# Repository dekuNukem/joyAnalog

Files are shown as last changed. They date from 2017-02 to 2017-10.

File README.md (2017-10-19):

# Custom circuit board for Joycon input automation



joyAnalog is a custom board with 12 analog switches and 2 12-bit DAC channels. Its main purpose is for automating Nintendo Switch Joycon inputs, and maybe TAS as well. 

joyAnalog presents itself to PC as a virtual USB serial port, so no special drivers are needed. Simply connect the button and joystick test points to the headers to allow the Joycon be controlled from a PC.

## Specs

* STM32F072C8T6 microcontroller, 16KB RAM, 64KB ROM
* 2x ADG714 SPI analog switch
* 1KB I2C EEPROM
* Automatic power switching
* User LED and button

## Header mappings

See [this PDF](datasheets/header_mapping.pdf).

## Twitch Plays Nintendo Switch

I dug up and reused a portion of my old code for TwitchPlaysPokemonX, [see here](./TwitchPlaysNintendoSwitch).

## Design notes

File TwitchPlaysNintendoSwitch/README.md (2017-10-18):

# Twitch Plays Nintendo Switch

This is actually a simplified version of the code used during Twitch Plays Pokemon X back in 2014. To keep it simple I used  tkinter for the command scroller. 

To use it:

* Connect the two correctly configured NintenDAC mini board to the computer.

* Open up `launch.py` in an editor and configure the username, oauth, chat channel and serial port name.

* Open up `banned_user.txt` and `disabled_cmd.txt` and fill them in as you wish. These can be updated while main script is running too.

* Run `python3 launch.py`

This script was tested under windows 10, it should work in macOS and linux too.

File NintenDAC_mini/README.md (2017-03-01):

## NintenDAC mini

This is the board that's to be used on modifying the Joycon. It's small enough to be taped to the back of each one.



* 48MHz STM32F072C8T6 microcontroller, 64KB flash, 16KB RAM.
* Built-in 2-channel 12-bit DAC.
* 1KB I2C EEPROM, user button, user LED.
* 28 GPIOs(or 32 using internal oscillators), BOOT0, RESET, VBAT, and SWD.
* USB for power and communication, standby wakeup on USB connection.
* Board size 2.5 x 4.1 cm, 1 x 1.6 inch.

## Command protocol

NintenDAC mini uses a simple serial command protocol. To use it open the port at any baud rate, then send a command in ASCII string. The board will send a response back.

Commands should be in lower case, and end with a single `\n`.

### Commands

**command**|**arguments**|**remark**|**response**|**example**
:-----:|:-----:|:-----:|:-----:|:-----:
`eepinit`|none|initializes EEPROM to default value|`eepinit OK`|`eepinit`
`settype`|l / r|set this board as left or right Joycon|`settype OK`|`settype l`
`whoami`|none|see which side is this board|A string containing `LEFT` or `RIGHT`; `unknown` if incorrectly set up|`whoami`
`bh`|button args (see below)|hold button|`bh OK` if no error; `ERROR`  otherwise|`bh a b x`
`br`|button args (see below)|release button|`br OK` if no error; `ERROR` otherwise|`br a b x`
`bra`|none|release all buttons on this board|`bra OK`|`bra`
`sh`|x y|move stick to x and y value. x y should be between 0 and 255 inclusive; 127 is netural position|`bh OK`|`sh 127 245`
`sr`|none|move stick back to netural position|`br OK`|`sr`
`sd`|none|stick disengage|`sd OK`|`sd`
`reset`|none|release all buttons as well as disengage the stick|`reset OK`|`reset`

### Button args

**arg**|**button**
:-----:|:-----:
`du`|D-pad up
`dd`|D-pad down
`dl`|D-pad left
`dr`|D-pad right
`ls`|L button
`zl`|ZL button
`-`|minus button 
`cap`|capture button
`lsl`|left Joycon SL button
`lsr`|left Joycon SR button
`syncl`|left Joycon SYNC button
`sbl`|left Joycon stick button
`a`|A button
`b`|B button
`x`|X button
`y`|Y button
`rs`|R button
`zr`|ZR button
`+`|plus button
`h`|home button
`rsl`|right Joycon SL button
`rsr`|right Joycon SR button
`syncr`|right Joycon SYNC button
`sbr`|right Joycon stick button

### A few words about commands

* `sh` and `sr` will take over the control stick, meaning the input won't change when you move the stick with your finger when those commands are active. To get back to manual control use `sd`

* Not all buttons are available on one board. For example if you try to `bh a` on a left Joycon board, you will get an error because there is no A button on left Joycon.

* `bh` and `br` can have one or multiple arguments, as long as they are all valid. So you can have `bh a` or `bh a b x y zr h +` etc. The max number of arguments is 16.

## NintenDAC Python3 library

I also wrote a [python3 library](./pythonlib) so you don't have to remember all the commands above. It requires `pyserial`.

A simple example:

```
import ndacmini

switch = ndacmini.ndacmini("COM5", "COM6")
switch.connect()

switch.button_hold(['a', 'b', 'zl', 'zr'])
switch.stick_hold('l', 64, 192)
switch.reset()
switch.disconnect()

```

A more detailed example with comments can be found [here](./pythonlib/example.py)

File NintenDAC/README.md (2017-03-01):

## NintenDAC

This is the bigger board that could be used on modifying the pro controller, or the console itself. It has more GPIOs than the mini, and has 10 channels of high speed DAC output.



* 48MHz STM32F072R8T6 microcontroller, 64KB flash, 16KB RAM.
* MAX5723/MAX5724/MAX5725 8-channel high-speed SPI DAC + 2-channel built-in DAC.
* 1KB I2C EEPROM, user button, user LED.
* 36 GPIOs(or 40 using internal oscillators), BOOT0, RESET, VBAT, and SWD.
* USB for power and communication, standby wakeup on USB connection.
* Board size 4.1 x 4.1 cm, or 1.65 x 1.65 inch.

## Command protocol

NintenDAC uses a simple serial command protocol. To use it open the port at any baud rate, then send a command in ASCII string. The board will send a respond back.

Commands should be in lower case, and end with a single `\n`.

### Commands

**command**|**arguments**|**remark**|**response**|**example**
:-----:|:-----:|:-----:|:-----:|:-----:
`eepinit`|none|initializes EEPROM to default value|`eepinit OK`|`eepinit`
`settype`|l / r|set this board as left or right Joycon|`settype OK`|`settype l`
`whoami`|none|see which side is this board|A string containing `LEFT` or `RIGHT`; `unknown` if incorrectly set up|`whoami`
`bh`|button args (see below)|hold button|`bh OK` if no error; `ERROR`  otherwise|`bh a b x`
`br`|button args (see below)|release button|`br OK` if no error; `ERROR` otherwise|`br a b x`
`bra`|none|release all buttons on this board|`bra OK`|`bra`
`reset`|none|release all buttons as well as disengage the stick|`reset OK`|`reset`

---under construction---under construction---

### Button args

**arg**|**button**
:-----:|:-----:
`du`|D-pad up
`dd`|D-pad down
`dl`|D-pad left
`dr`|D-pad right
`ls`|L button
`zl`|ZL button
`-`|minus button 
`cap`|capture button
`sbl`|left stick button
`a`|A button
`b`|B button
`x`|X button
`y`|Y button
`rs`|R button
`zr`|ZR button
`+`|plus button
`h`|home button
`sbr`|right stick button
`sync`|SYNC button

### A few words about commands

* `sh` and `sr` will take over the control stick, meaning the input won't change when you move the stick with your finger when those commands are active. To get back to manual control use `sd`

* `bh` and `br` can have one or multiple arguments, as long as they are all valid. So you can have `bh a` or `bh a b x y zr h +` etc. The max number of arguments is 16.

---under construction---under construction---

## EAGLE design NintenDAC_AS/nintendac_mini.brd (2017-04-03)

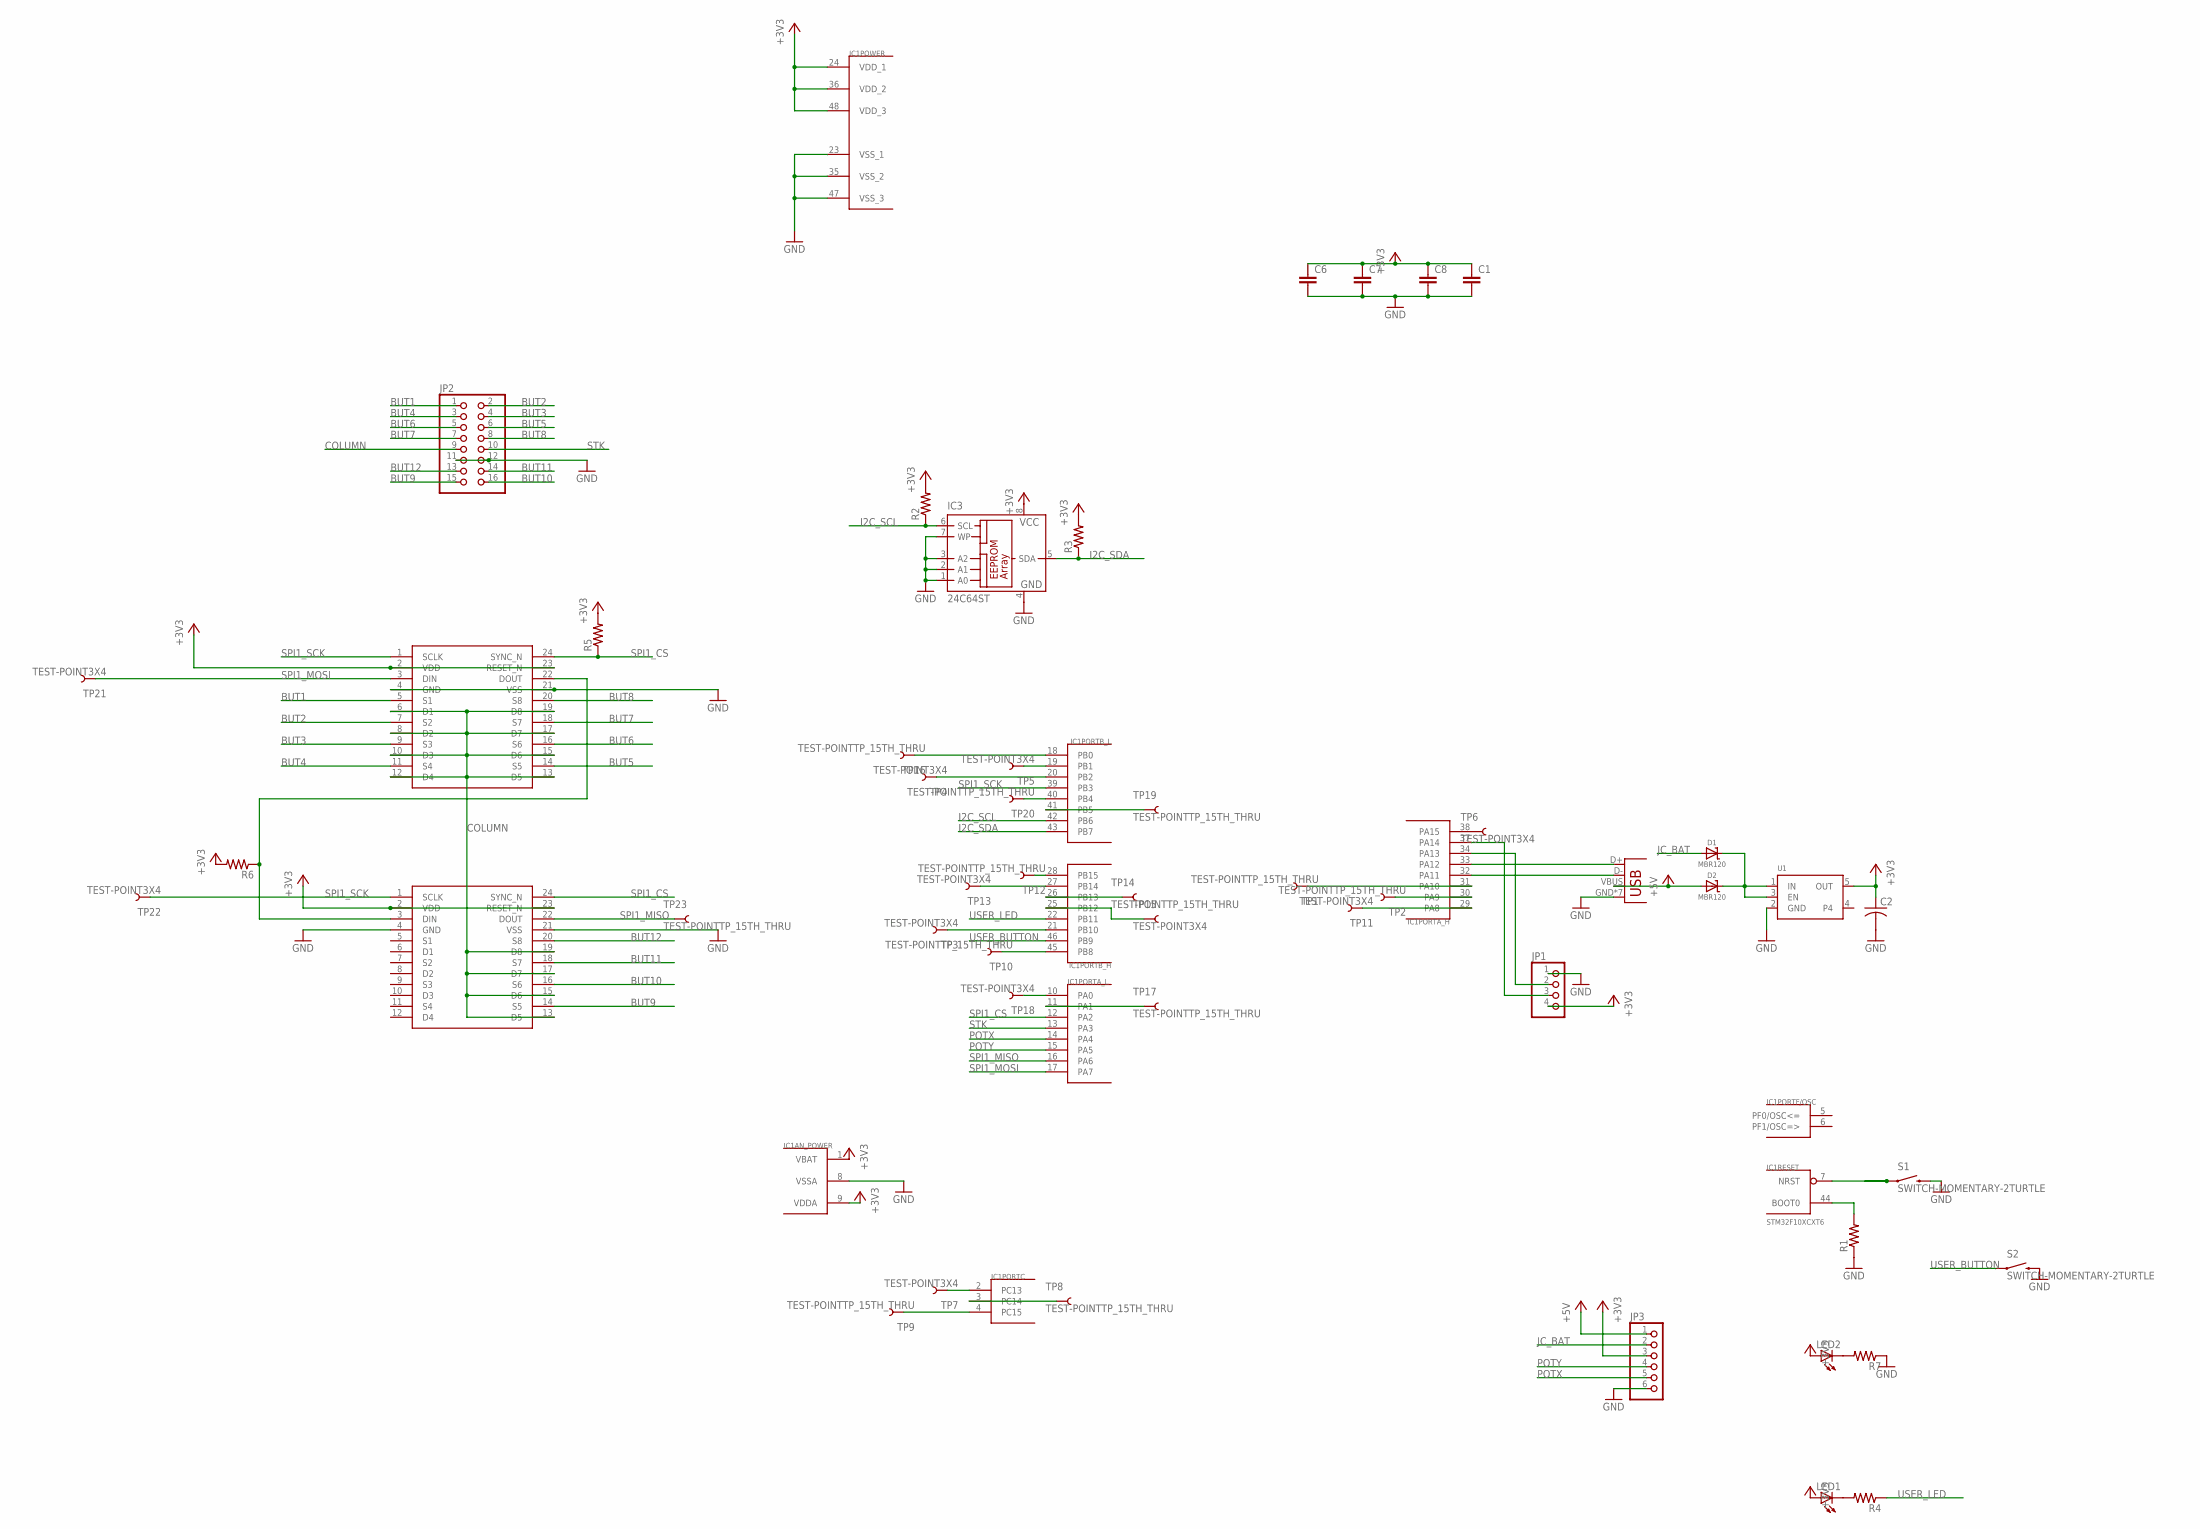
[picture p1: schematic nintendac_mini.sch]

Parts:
C1, C6, C7, C8: CAP0805; 0805
C2: C-USC1210; C1210
D1, D2: MBR120; SOD-123
IC1: STM32F10XCXT6; TQFP48
IC3: 24C64ST; TSSOP8
JP1: PINHD-1X4; 1X04
JP2: PINHD-2X8; 2X08
JP3: PINHD-1X6CB; 1X06-CLEANBIG
LED1, LED2: LEDCHIP-LED0805; CHIP-LED0805
R1, R2, R3, R4, R5, R6, R7: RESISTOR0805-RES; 0805
S1, S2: SWITCH-MOMENTARY-2TURTLE; KMR2
TP1, TP2, TP8, TP9, TP10, TP12, TP14, TP16, TP17, TP19, TP20, TP23: TEST-POINTTP_15TH_THRU; TP_15TH
TP3, TP4, TP5, TP6, TP7, TP11, TP13, TP15, TP18, TP21, TP22: TEST-POINT3X4; PAD.03X.04
U1: VREG_SOT23-5; SOT23-5
U$3, U$4: ADG714_DEV; TSSOP-24
X1: USB-MICROB

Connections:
+3V3: C1.1, C2.1, C6.1, C7.1, C8.1, IC1.1 (VBAT), IC1.9 (VDDA), IC1.24 (VDD_1), IC1.36 (VDD_2), IC1.48 (VDD_3), IC3.8 (VCC), JP1.4, JP3.3, LED1.A, LED2.A, R2.2, R3.2, R5.2, R6.2, U1.5 (OUT), U$3.2 (VDD), U$3.23 (RESET_N), U$4.2 (VDD), U$4.23 (RESET_N)
+5V: D2.A, JP3.1, X1.VBUS
BUT1: JP2.1, U$3.5 (S1)
BUT2: JP2.2, U$3.7 (S2)
BUT3: JP2.4, U$3.9 (S3)
BUT4: JP2.3, U$3.11 (S4)
BUT5: JP2.6, U$3.14 (S5)
BUT6: JP2.5, U$3.16 (S6)
BUT7: JP2.7, U$3.18 (S7)
BUT8: JP2.8, U$3.20 (S8)
BUT9: JP2.15, U$4.14 (S5)
BUT10: JP2.16, U$4.16 (S6)
BUT11: JP2.14, U$4.18 (S7)
BUT12: JP2.13, U$4.20 (S8)
COLUMN: JP2.9, U$3.6 (D1), U$3.8 (D2), U$3.10 (D3), U$3.12 (D4), U$3.13 (D5), U$3.15 (D6), U$3.17 (D7), U$3.19 (D8), U$4.13 (D5), U$4.15 (D6), U$4.17 (D7), U$4.19 (D8)
GND: C1.2, C2.2, C6.2, C7.2, C8.2, IC1.8 (VSSA), IC1.23 (VSS_1), IC1.35 (VSS_2), IC1.47 (VSS_3), IC3.1 (A0), IC3.2 (A1), IC3.3 (A2), IC3.4 (GND), IC3.7 (WP), JP1.1, JP2.11, JP2.12, JP3.6, R1.1, R7.1, S1.3 (2), S2.3 (2), U1.2 (GND), U$3.4 (GND), U$3.21 (VSS), U$4.4 (GND), U$4.21 (VSS), X1.GND, X1.P1 (GND), X1.P2 (GND), X1.P3 (GND), X1.P4 (GND), X1.P5 (GND), X1.P6 (GND)
I2C_SCL: IC1.42 (PB6), IC3.6 (SCL), R2.1
I2C_SDA: IC1.43 (PB7), IC3.5 (SDA), R3.1
JC_BAT: D1.A, JP3.2
unnamed: IC1.7 (NRST), S1.1
unnamed: IC1.44 (BOOT0), R1.2
unnamed: LED1.C, R4.2
unnamed: IC1.33 (PA12), X1.D+
unnamed: R6.1, U$3.22 (DOUT), U$4.3 (DIN)
unnamed: IC1.30 (PA9), TP2.P$1
unnamed: IC1.32 (PA11), X1.D-
unnamed: IC1.34 (PA13), JP1.2
unnamed: IC1.37 (PA14), JP1.3
unnamed: IC1.31 (PA10), TP1.P$1
unnamed: IC1.20 (PB2), TP4.P$1
unnamed: IC1.19 (PB1), TP5.P$1
unnamed: IC1.21 (PB10), TP3.P$1
unnamed: IC1.38 (PA15), TP6.P$1
unnamed: IC1.2 (PC13), TP7.P$1
unnamed: IC1.3 (PC14), TP8.P$1
unnamed: IC1.4 (PC15), TP9.P$1
unnamed: IC1.45 (PB8), TP10.P$1
unnamed: IC1.29 (PA8), TP11.P$1
unnamed: IC1.28 (PB15), TP12.P$1
unnamed: IC1.27 (PB14), TP13.P$1
unnamed: IC1.26 (PB13), TP14.P$1
unnamed: IC1.25 (PB12), TP15.P$1
unnamed: IC1.18 (PB0), TP16.P$1
unnamed: IC1.10 (PA0), TP18.P$1
unnamed: IC1.11 (PA1), TP17.P$1
unnamed: IC1.40 (PB4), TP20.P$1
unnamed: IC1.41 (PB5), TP19.P$1
unnamed: LED2.C, R7.2
unnamed: D1.C, D2.C, U1.1 (IN), U1.3 (EN)
POTX: IC1.14 (PA4), JP3.5
POTY: IC1.15 (PA5), JP3.4
SPI1_CS: IC1.12 (PA2), R5.1, U$3.24 (SYNC_N), U$4.24 (SYNC_N)
SPI1_MISO: IC1.16 (PA6), TP23.P$1, U$4.22 (DOUT)
SPI1_MOSI: IC1.17 (PA7), TP21.P$1, U$3.3 (DIN)
SPI1_SCK: IC1.39 (PB3), TP22.P$1, U$3.1 (SCLK), U$4.1 (SCLK)
STK: IC1.13 (PA3), JP2.10
USER_BUTTON: IC1.46 (PB9), S2.1
USER_LED: IC1.22 (PB11), R4.1

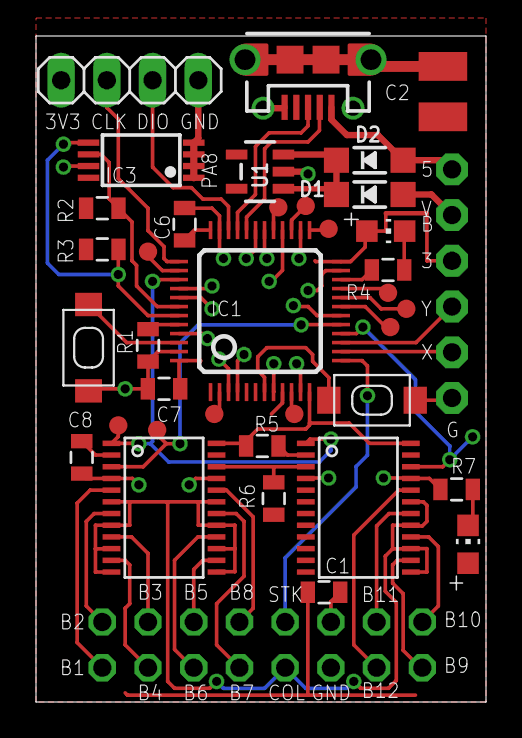
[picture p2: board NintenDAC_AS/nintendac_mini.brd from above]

Board: 2 copper layers, 25.0 x 37.0 mm, 50 parts (0 on the bottom side), 58 nets.

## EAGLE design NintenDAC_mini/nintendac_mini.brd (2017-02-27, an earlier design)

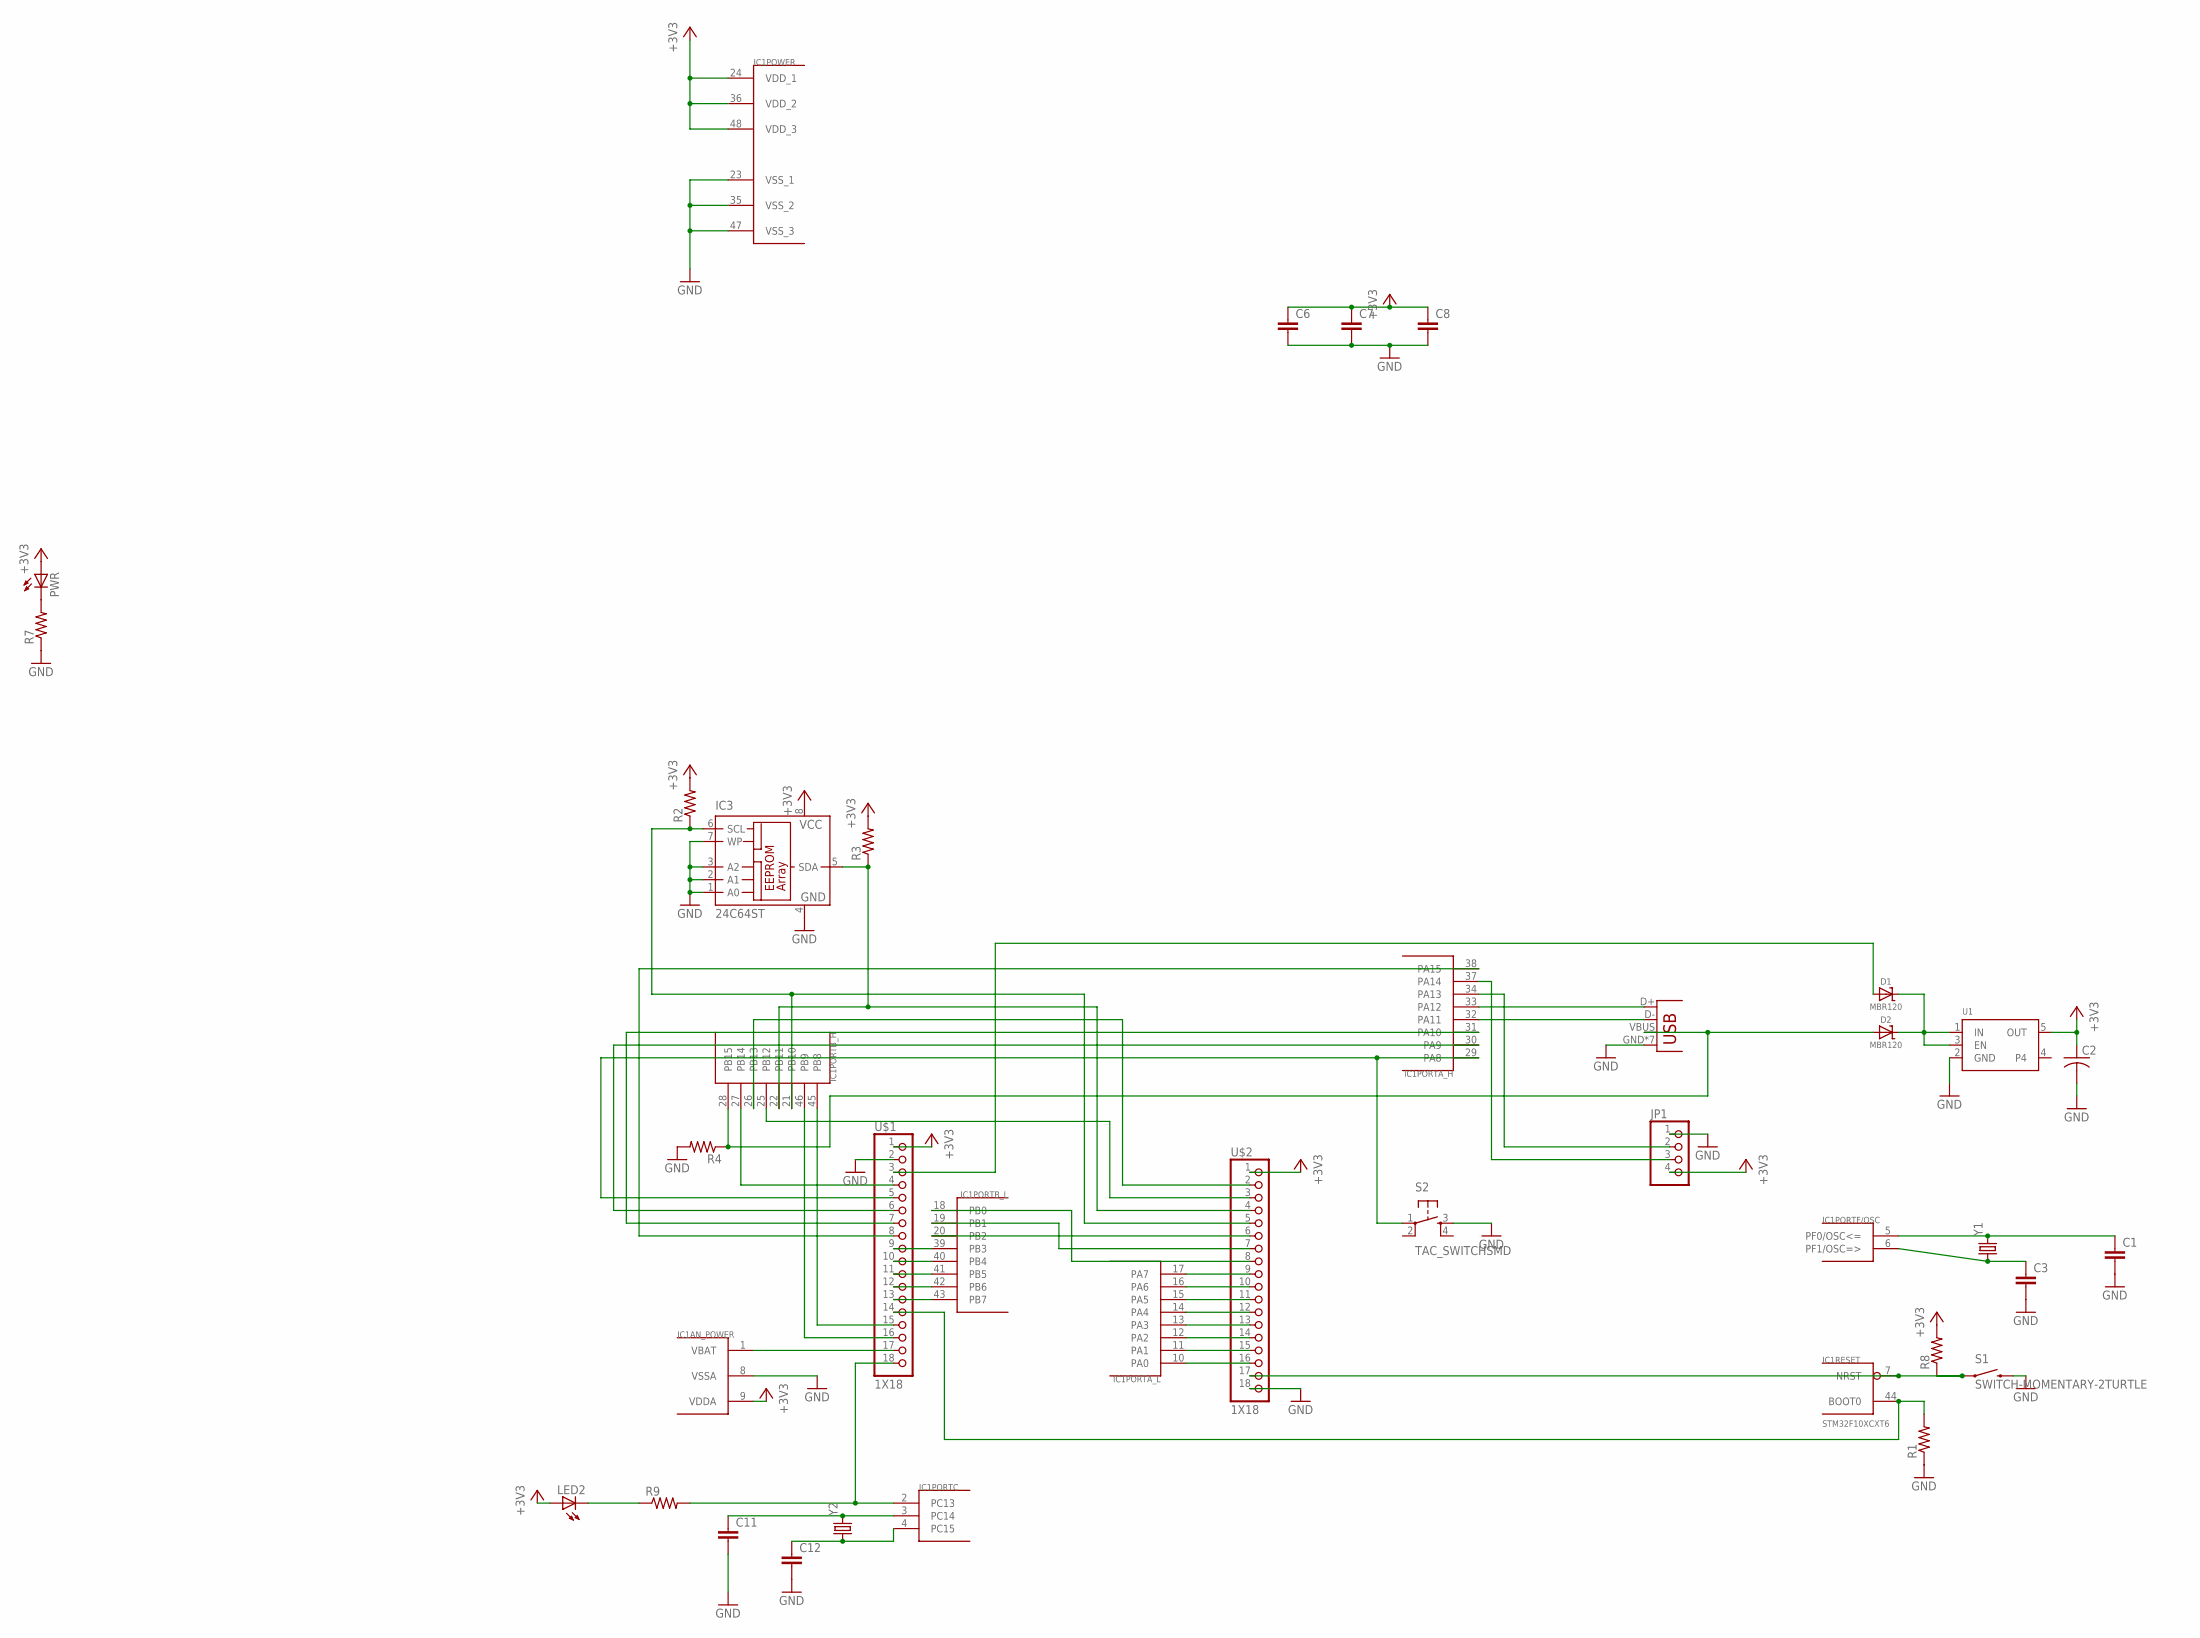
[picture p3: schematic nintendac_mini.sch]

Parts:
C1, C3, C6, C7, C8, C11, C12: CAP0805; 0805
C2: C-USC1210; C1210
D1, D2: MBR120; SOD-123
IC1: STM32F10XCXT6; TQFP48
IC3: 24C64ST; TSSOP8
JP1: PINHD-1X4; 1X04
LED2: LEDCHIP-LED0805; CHIP-LED0805
PWR: LEDCHIP-LED0805; CHIP-LED0805
R1, R2, R3, R4, R7, R8, R9: RESISTOR0805-RES; 0805
S1: SWITCH-MOMENTARY-2TURTLE; KMR2
S2: TAC_SWITCHSMD; TACTILE-SWITCH-SMD
U1: VREG_SOT23-5; SOT23-5
U$1, U$2: 1X18
X1: USB-MICROB
Y1: CRYSTALHC49US; HC49US
Y2: CRYSTALTC26H_EZ; TC26HEZ

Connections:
+3V3: C2.1, C6.1, C7.1, C8.1, IC1.9 (VDDA), IC1.24 (VDD_1), IC1.36 (VDD_2), IC1.48 (VDD_3), IC3.8 (VCC), JP1.4, LED2.A, PWR.A, R2.2, R3.2, R8.2, U1.5 (OUT), U$1.1, U$2.1
GND: C1.2, C2.2, C3.2, C6.2, C7.2, C8.2, C11.2, C12.2, IC1.8 (VSSA), IC1.23 (VSS_1), IC1.35 (VSS_2), IC1.47 (VSS_3), IC3.1 (A0), IC3.2 (A1), IC3.3 (A2), IC3.4 (GND), IC3.7 (WP), JP1.1, R1.1, R4.2, R7.1, S1.3 (2), S2.3, U1.2 (GND), U$1.2, U$2.18, X1.GND, X1.P1 (GND), X1.P2 (GND), X1.P3 (GND), X1.P4 (GND), X1.P5 (GND), X1.P6 (GND)
unnamed: IC1.7 (NRST), R8.1, S1.1, U$2.17
unnamed: D1.A, U$1.3
unnamed: IC1.44 (BOOT0), R1.2, U$1.14
unnamed: IC1.33 (PA12), X1.D+
unnamed: C1.1, IC1.5 (PF0/OSC<=), Y1.2
unnamed: C3.1, IC1.6 (PF1/OSC=>), Y1.1
unnamed: IC1.32 (PA11), X1.D-
unnamed: IC1.34 (PA13), JP1.2
unnamed: IC1.37 (PA14), JP1.3
unnamed: IC1.10 (PA0), U$2.16
unnamed: IC1.11 (PA1), U$2.15
unnamed: IC1.12 (PA2), U$2.14
unnamed: IC1.13 (PA3), U$2.13
unnamed: IC1.14 (PA4), U$2.12
unnamed: IC1.15 (PA5), U$2.11
unnamed: IC1.16 (PA6), U$2.10
unnamed: IC1.17 (PA7), U$2.9
unnamed: IC1.21 (PB10), IC3.6 (SCL), R2.1, U$2.5
unnamed: IC1.22 (PB11), IC3.5 (SDA), R3.1, U$2.4
unnamed: IC1.18 (PB0), U$2.8
unnamed: IC1.19 (PB1), U$2.7
unnamed: IC1.20 (PB2), U$2.6
unnamed: IC1.43 (PB7), U$1.13
unnamed: IC1.42 (PB6), U$1.12
unnamed: IC1.41 (PB5), U$1.11
unnamed: IC1.40 (PB4), U$1.10
unnamed: PWR.C, R7.2
unnamed: C11.1, IC1.3 (PC14), Y2.2
unnamed: C12.1, IC1.4 (PC15), Y2.1
unnamed: IC1.39 (PB3), U$1.9
unnamed: D1.C, D2.C, U1.1 (IN), U1.3 (EN)
unnamed: IC1.2 (PC13), R9.2, U$1.18
unnamed: IC1.1 (VBAT), U$1.17
unnamed: IC1.46 (PB9), U$1.16
unnamed: IC1.45 (PB8), U$1.15
unnamed: IC1.25 (PB12), U$2.3
unnamed: IC1.26 (PB13), U$2.2
unnamed: IC1.38 (PA15), U$1.8
unnamed: IC1.31 (PA10), U$1.7
unnamed: IC1.30 (PA9), U$1.6
unnamed: IC1.29 (PA8), S2.1, U$1.5
unnamed: IC1.27 (PB14), U$1.4
unnamed: D2.A, IC1.28 (PB15), R4.1, X1.VBUS
unnamed: LED2.C, R9.1

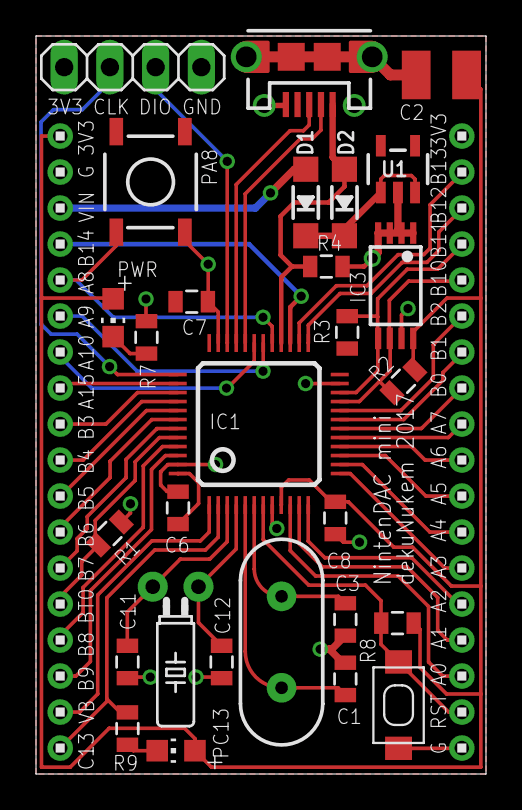
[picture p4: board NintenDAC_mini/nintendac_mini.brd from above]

Board: 2 copper layers, 25.0 x 41.0 mm, 30 parts (0 on the bottom side), 46 nets.

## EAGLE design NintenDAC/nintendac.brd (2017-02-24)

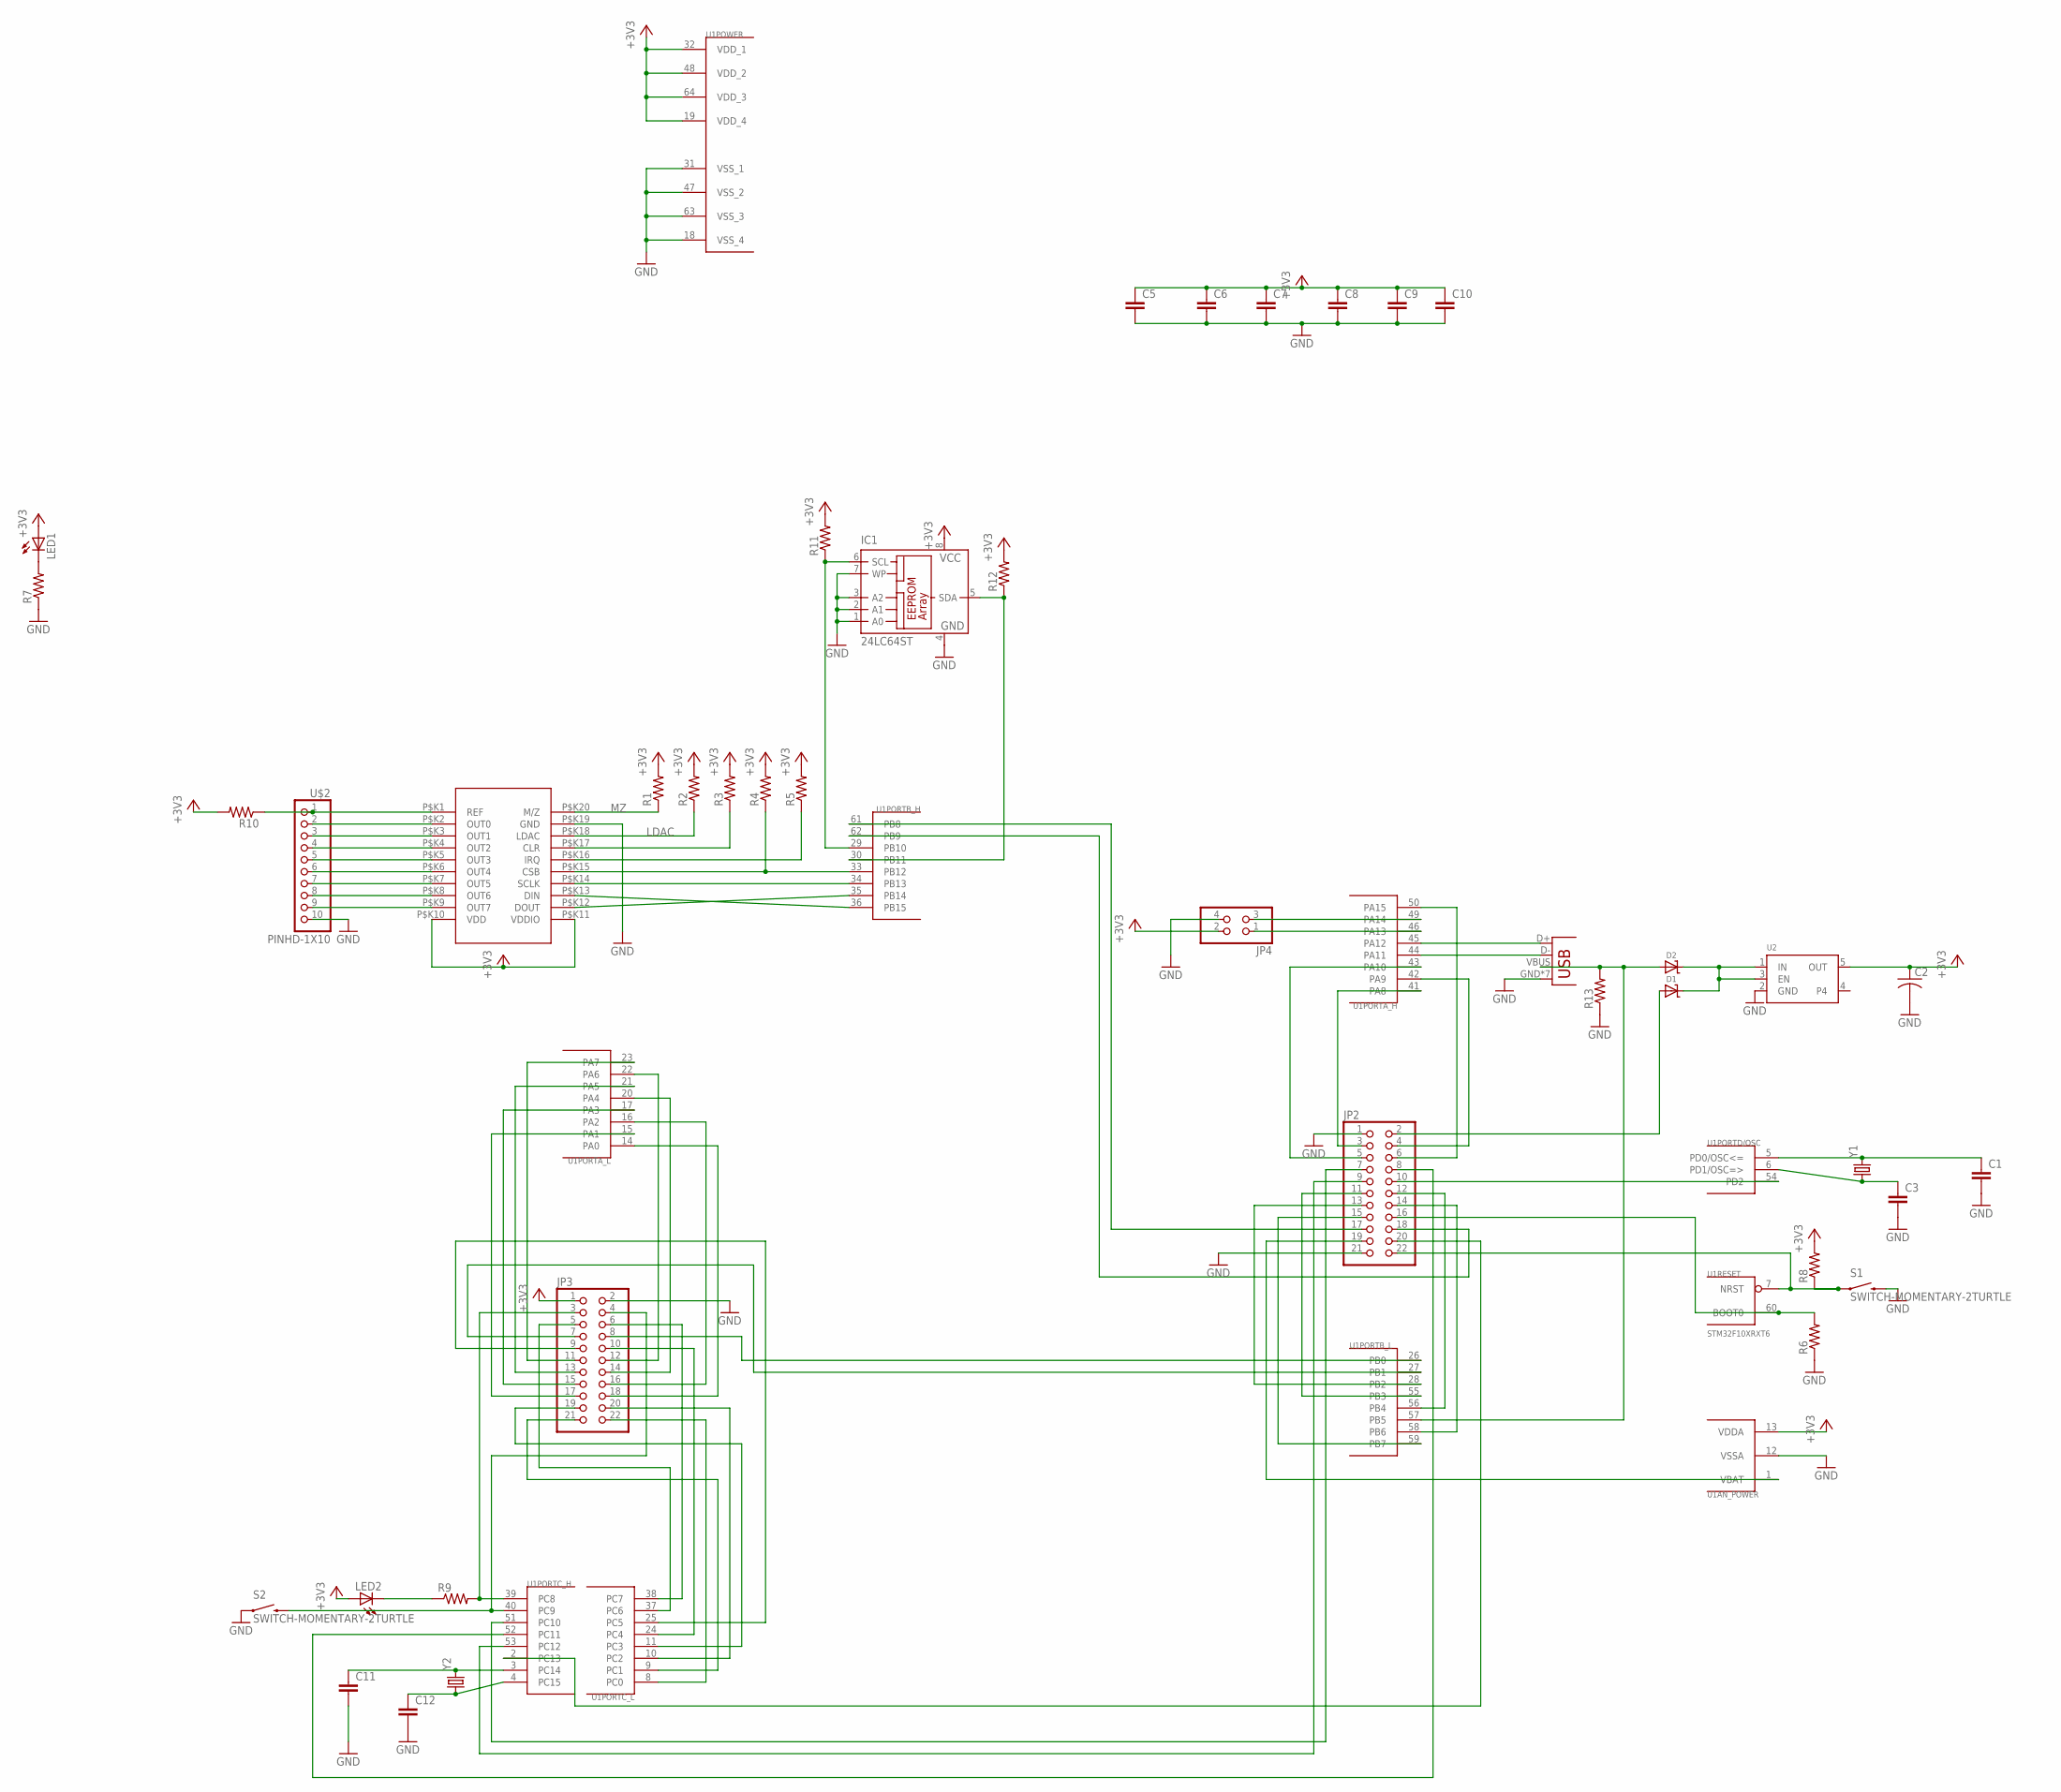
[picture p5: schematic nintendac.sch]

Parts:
C1, C3, C5, C6, C7, C8, C9, C10, C11, C12: CAP0805; 0805
C2: C-USC1210; C1210
D1, D2: DIODE-SCHOTTKYSOD-123; SOD-123
IC1: 24LC64ST; TSSOP8
JP2, JP3: PINHD-2X11; 2X11
JP4: PINHD-2X2; 2X02
LED1, LED2: LEDCHIP-LED0805; CHIP-LED0805
R1, R2, R3, R4, R5, R6, R7, R8, R9, R10, R11, R12, R13: RESISTOR0805-RES; 0805
S1, S2: SWITCH-MOMENTARY-2TURTLE; KMR2
U1: STM32F10XRXT6; TQFP64
U2: VREG_SOT23-5; SOT23-5
U$1: MAX572X; TSSOP20
U$2: PINHD-1X10; 1X10-BIG
X1: USB-MICROB
Y1: CRYSTALHC49US; HC49US
Y2: CRYSTALTC26H_EZ; TC26HEZ

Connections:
+3V3: C2.1, C5.1, C6.1, C7.1, C8.1, C9.1, C10.1, IC1.8 (VCC), JP3.1, JP4.2, LED1.A, LED2.A, R1.2, R2.2, R3.2, R4.2, R5.2, R8.2, R10.2, R11.2, R12.2, U1.13 (VDDA), U1.19 (VDD_4), U1.32 (VDD_1), U1.48 (VDD_2), U1.64 (VDD_3), U2.5 (OUT), U$1.P$K10 (VDD), U$1.P$K11 (VDDIO)
GND: C1.2, C2.2, C3.2, C5.2, C6.2, C7.2, C8.2, C9.2, C10.2, C11.2, C12.2, IC1.1 (A0), IC1.2 (A1), IC1.3 (A2), IC1.4 (GND), IC1.7 (WP), JP2.1, JP2.21, JP3.2, JP4.4, R6.1, R7.1, R13.1, S1.3 (2), S2.1, U1.12 (VSSA), U1.18 (VSS_4), U1.31 (VSS_1), U1.47 (VSS_2), U1.63 (VSS_3), U2.2 (GND), U$1.P$K19 (GND), U$2.10, X1.GND, X1.P1 (GND), X1.P2 (GND), X1.P3 (GND), X1.P4 (GND), X1.P5 (GND), X1.P6 (GND)
LDAC: R2.1, U$1.P$K18 (LDAC)
MZ: R1.1, U$1.P$K20 (M/Z)
unnamed: JP2.22, R8.1, S1.1, U1.7 (NRST)
unnamed: D1.C, D2.C, U2.1 (IN), U2.3 (EN)
unnamed: U1.44 (PA11), X1.D-
unnamed: U1.45 (PA12), X1.D+
unnamed: C1.1, U1.5 (PD0/OSC<=), Y1.2
unnamed: C3.1, U1.6 (PD1/OSC=>), Y1.1
unnamed: R10.1, U$1.P$K1 (REF), U$2.1
unnamed: U$1.P$K2 (OUT0), U$2.2
unnamed: U$1.P$K3 (OUT1), U$2.3
unnamed: U$1.P$K4 (OUT2), U$2.4
unnamed: U$1.P$K5 (OUT3), U$2.5
unnamed: U$1.P$K6 (OUT4), U$2.6
unnamed: U$1.P$K7 (OUT5), U$2.7
unnamed: U$1.P$K8 (OUT6), U$2.8
unnamed: U$1.P$K9 (OUT7), U$2.9
unnamed: U1.36 (PB15), U$1.P$K13 (DIN)
unnamed: U1.35 (PB14), U$1.P$K12 (DOUT)
unnamed: U1.34 (PB13), U$1.P$K14 (SCLK)
unnamed: R4.1, U1.33 (PB12), U$1.P$K15 (CSB)
unnamed: R5.1, U$1.P$K16 (IRQ)
unnamed: R3.1, U$1.P$K17 (CLR)
unnamed: JP4.3, U1.49 (PA14)
unnamed: JP3.5, U1.37 (PC6)
unnamed: JP4.1, U1.46 (PA13)
unnamed: JP3.6, U1.38 (PC7)
unnamed: JP2.16, R6.2, U1.60 (BOOT0)
unnamed: LED1.C, R7.2
unnamed: C11.1, U1.3 (PC14), Y2.2
unnamed: C12.1, U1.4 (PC15), Y2.1
unnamed: JP3.4, S2.3 (2), U1.40 (PC9)
unnamed: JP2.3, U1.41 (PA8)
unnamed: JP3.3, R9.2, U1.39 (PC8)
unnamed: JP2.4, U1.42 (PA9)
unnamed: JP2.5, U1.43 (PA10)
unnamed: JP3.7, U1.27 (PB1)
unnamed: JP3.8, U1.26 (PB0)
unnamed: JP3.9, U1.25 (PC5)
unnamed: JP3.10, U1.24 (PC4)
unnamed: JP3.11, U1.23 (PA7)
unnamed: JP3.12, U1.22 (PA6)
unnamed: JP3.13, U1.21 (PA5)
unnamed: JP3.14, U1.20 (PA4)
unnamed: JP3.15, U1.17 (PA3)
unnamed: JP3.16, U1.16 (PA2)
unnamed: JP3.17, U1.15 (PA1)
unnamed: JP3.18, U1.14 (PA0)
unnamed: JP3.22, U1.8 (PC0)
unnamed: JP3.21, U1.9 (PC1)
unnamed: JP3.20, U1.10 (PC2)
unnamed: JP3.19, U1.11 (PC3)
unnamed: JP2.6, U1.50 (PA15)
unnamed: JP2.7, U1.51 (PC10)
unnamed: JP2.9, U1.53 (PC12)
unnamed: JP2.8, U1.52 (PC11)
unnamed: JP2.10, U1.54 (PD2)
unnamed: JP2.11, U1.55 (PB3)
unnamed: JP2.12, U1.56 (PB4)
unnamed: D2.A, R13.2, U1.57 (PB5), X1.VBUS
unnamed: JP2.14, U1.58 (PB6)
unnamed: JP2.15, U1.59 (PB7)
unnamed: JP2.17, U1.61 (PB8)
unnamed: JP2.18, U1.62 (PB9)
unnamed: JP2.19, U1.1 (VBAT)
unnamed: JP2.20, U1.2 (PC13)
unnamed: LED2.C, R9.1
unnamed: D1.A, JP2.2
unnamed: IC1.6 (SCL), R11.1, U1.29 (PB10)
unnamed: IC1.5 (SDA), R12.1, U1.30 (PB11)
unnamed: JP2.13, U1.28 (PB2)

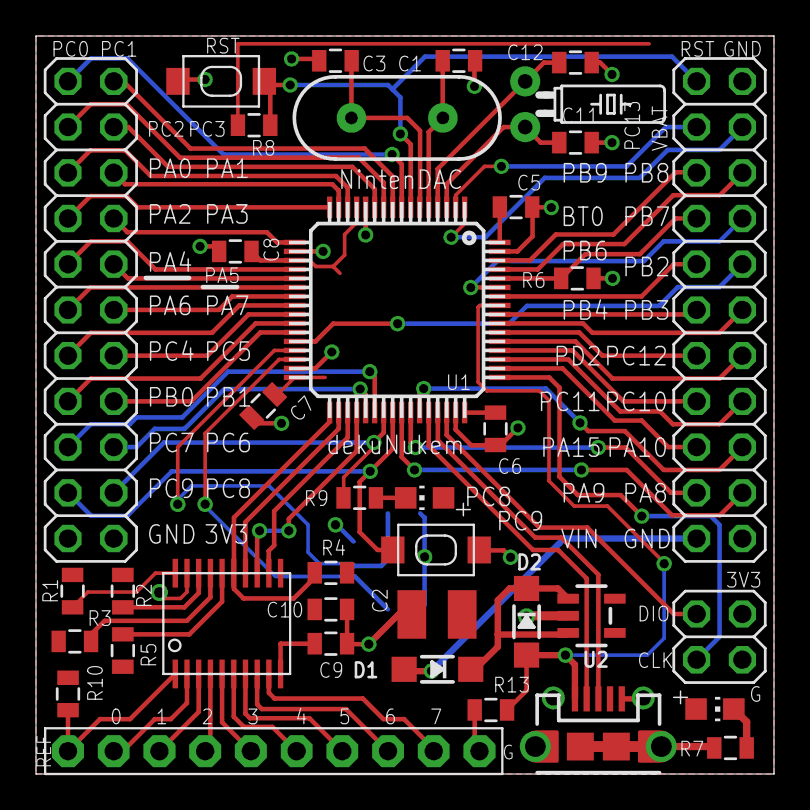
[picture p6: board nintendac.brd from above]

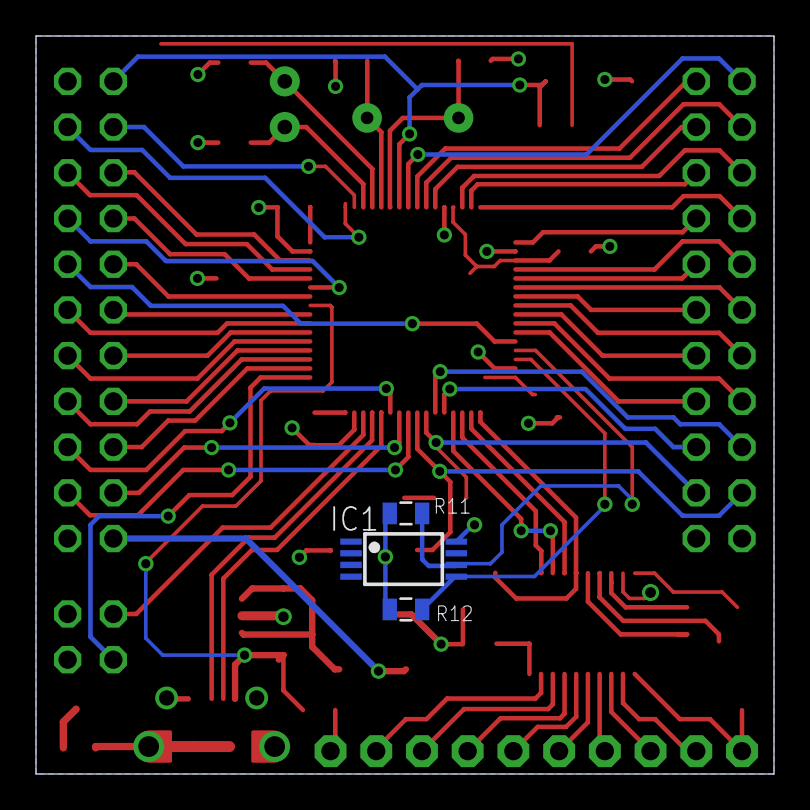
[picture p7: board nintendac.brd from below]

Board: 2 copper layers, 41.0 x 41.0 mm, 41 parts (3 on the bottom side), 73 nets.

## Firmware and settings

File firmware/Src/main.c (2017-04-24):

/**
  ******************************************************************************
  * File Name          : main.c
  * Description        : Main program body
  ******************************************************************************
  *
  * Copyright (c) 2017 STMicroelectronics International N.V. 
  * All rights reserved.
  *
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
  ******************************************************************************
  */
/* Includes ------------------------------------------------------------------*/
#include "main.h"
#include "stm32f0xx_hal.h"
#include "usb_device.h"

/* USER CODE BEGIN Includes */

#include "shared.h"
#include "my_usb.h"
#include "helpers.h"
#include "jc_ctrl.h"
#include "eeprom.h"
#include "cmd_parser.h"

/* USER CODE END Includes */

DAC_HandleTypeDef hdac;

I2C_HandleTypeDef hi2c1;

IWDG_HandleTypeDef hiwdg;

SPI_HandleTypeDef hspi1;

/* USER CODE BEGIN PV */
int32_t board_type, next_kick;
/* USER CODE END PV */

void SystemClock_Config(void);
void Error_Handler(void);
static void MX_GPIO_Init(void);
static void MX_I2C1_Init(void);
static void MX_SPI1_Init(void);
static void MX_IWDG_Init(void);

/* USER CODE BEGIN PFP */
static void MX_DAC_Init(void);
/* USER CODE END PFP */

/* USER CODE BEGIN 0 */
void kick_dog(void)
{
  if(HAL_GetTick() > next_kick)
  {
    HAL_IWDG_Refresh(&hiwdg);
    next_kick = HAL_GetTick() + 500;
  }
}

void stm32_dac_init(void)
{
  MX_DAC_Init();
  HAL_DAC_Start(dac_ptr, DAC_CHANNEL_1);
  HAL_DAC_Start(dac_ptr, DAC_CHANNEL_2);
}

int fputc(int ch, FILE *f)
{
  my_usb_putchar((uint8_t)ch);
  return ch;
}
/* USER CODE END 0 */

int main(void)
{

  /* MCU Configuration----------------------------------------------------------*/

  /* Reset of all peripherals, Initializes the Flash interface and the Systick. */
  HAL_Init();

  /* Configure the system clock */
  SystemClock_Config();

  /* Initialize all configured peripherals */
  MX_GPIO_Init();
  MX_I2C1_Init();
  MX_SPI1_Init();
  MX_USB_DEVICE_Init();
  MX_IWDG_Init();

  /* USER CODE BEGIN 2 */
  my_usb_init();
  board_type = eeprom_read(EEPROM_BOARD_TYPE_ADDR);
  jc_ctrl_init();
  stick_release();
  for (int i = 0; i < 6; ++i)
  {
    HAL_GPIO_TogglePin(USER_LED_GPIO_Port, USER_LED_Pin);
    HAL_Delay(100);
  }
  /* USER CODE END 2 */

  /* Infinite loop */
  /* USER CODE BEGIN WHILE */
  
  while (1)
  {
    kick_dog();
  /* USER CODE END WHILE */

  /* USER CODE BEGIN 3 */
    usb_data = my_usb_readline();
    if(usb_data == NULL)
      continue;
    parse_cmd(usb_data);
  }
  /* USER CODE END 3 */

}

/** System Clock Configuration
*/
void SystemClock_Config(void)
{

  RCC_OscInitTypeDef RCC_OscInitStruct;
  RCC_ClkInitTypeDef RCC_ClkInitStruct;
  RCC_PeriphCLKInitTypeDef PeriphClkInit;

    /**Initializes the CPU, AHB and APB busses clocks 
    */
  RCC_OscInitStruct.OscillatorType = RCC_OSCILLATORTYPE_HSI48
                              |RCC_OSCILLATORTYPE_LSI;
  RCC_OscInitStruct.HSI48State = RCC_HSI48_ON;
  RCC_OscInitStruct.LSIState = RCC_LSI_ON;
  RCC_OscInitStruct.PLL.PLLState = RCC_PLL_NONE;
  if (HAL_RCC_OscConfig(&RCC_OscInitStruct) != HAL_OK)
  {
    Error_Handler();
  }

    /**Initializes the CPU, AHB and APB busses clocks 
    */
  RCC_ClkInitStruct.ClockType = RCC_CLOCKTYPE_HCLK|RCC_CLOCKTYPE_SYSCLK
                              |RCC_CLOCKTYPE_PCLK1;
  RCC_ClkInitStruct.SYSCLKSource = RCC_SYSCLKSOURCE_HSI48;
  RCC_ClkInitStruct.AHBCLKDivider = RCC_SYSCLK_DIV1;
  RCC_ClkInitStruct.APB1CLKDivider = RCC_HCLK_DIV1;

  if (HAL_RCC_ClockConfig(&RCC_ClkInitStruct, FLASH_LATENCY_1) != HAL_OK)
  {
    Error_Handler();
  }

  PeriphClkInit.PeriphClockSelection = RCC_PERIPHCLK_USB|RCC_PERIPHCLK_USART1
                              |RCC_PERIPHCLK_I2C1;
  PeriphClkInit.I2c1ClockSelection = RCC_I2C1CLKSOURCE_SYSCLK;
  PeriphClkInit.UsbClockSelection = RCC_USBCLKSOURCE_HSI48;

  if (HAL_RCCEx_PeriphCLKConfig(&PeriphClkInit) != HAL_OK)
  {
    Error_Handler();
  }

    /**Configure the Systick interrupt time 
    */
  HAL_SYSTICK_Config(HAL_RCC_GetHCLKFreq()/1000);

    /**Configure the Systick 
    */
  HAL_SYSTICK_CLKSourceConfig(SYSTICK_CLKSOURCE_HCLK);

  /* SysTick_IRQn interrupt configuration */
  HAL_NVIC_SetPriority(SysTick_IRQn, 0, 0);
}

/* DAC init function */
static void MX_DAC_Init(void)
{

  DAC_ChannelConfTypeDef sConfig;

    /**DAC Initialization 
    */
  hdac.Instance = DAC;
  if (HAL_DAC_Init(&hdac) != HAL_OK)
  {
    Error_Handler();
  }

    /**DAC channel OUT1 config 
    */
  sConfig.DAC_Trigger = DAC_TRIGGER_NONE;
  sConfig.DAC_OutputBuffer = DAC_OUTPUTBUFFER_ENABLE;
  if (HAL_DAC_ConfigChannel(&hdac, &sConfig, DAC_CHANNEL_1) != HAL_OK)
  {
    Error_Handler();
  }

    /**DAC channel OUT2 config 
    */
  if (HAL_DAC_ConfigChannel(&hdac, &sConfig, DAC_CHANNEL_2) != HAL_OK)
  {
    Error_Handler();
  }

}

/* I2C1 init function */
static void MX_I2C1_Init(void)
{

  hi2c1.Instance = I2C1;
  hi2c1.Init.Timing = 0x20303E5D;
  hi2c1.Init.OwnAddress1 = 0;
  hi2c1.Init.AddressingMode = I2C_ADDRESSINGMODE_7BIT;
  hi2c1.Init.DualAddressMode = I2C_DUALADDRESS_DISABLE;
  hi2c1.Init.OwnAddress2 = 0;
  hi2c1.Init.OwnAddress2Masks = I2C_OA2_NOMASK;
  hi2c1.Init.GeneralCallMode = I2C_GENERALCALL_DISABLE;
  hi2c1.Init.NoStretchMode = I2C_NOSTRETCH_DISABLE;
  if (HAL_I2C_Init(&hi2c1) != HAL_OK)
  {
    Error_Handler();
  }

    /**Configure Analogue filter 
    */
  if (HAL_I2CEx_ConfigAnalogFilter(&hi2c1, I2C_ANALOGFILTER_ENABLE) != HAL_OK)
  {
    Error_Handler();
  }

    /**Configure Digital filter 
    */
  if (HAL_I2CEx_ConfigDigitalFilter(&hi2c1, 0) != HAL_OK)
  {
    Error_Handler();
  }

}

/* IWDG init function */
static void MX_IWDG_Init(void)
{

  hiwdg.Instance = IWDG;
  hiwdg.Init.Prescaler = IWDG_PRESCALER_16;
  hiwdg.Init.Window = 4095;
  hiwdg.Init.Reload = 4095;
  if (HAL_IWDG_Init(&hiwdg) != HAL_OK)
  {
    Error_Handler();
  }

}

/* SPI1 init function */
static void MX_SPI1_Init(void)
{

  hspi1.Instance = SPI1;
  hspi1.Init.Mode = SPI_MODE_MASTER;
  hspi1.Init.Direction = SPI_DIRECTION_2LINES;
  hspi1.Init.DataSize = SPI_DATASIZE_8BIT;
  hspi1.Init.CLKPolarity = SPI_POLARITY_LOW;
  hspi1.Init.CLKPhase = SPI_PHASE_2EDGE;
  hspi1.Init.NSS = SPI_NSS_SOFT;
  hspi1.Init.BaudRatePrescaler = SPI_BAUDRATEPRESCALER_4;
  hspi1.Init.FirstBit = SPI_FIRSTBIT_MSB;
  hspi1.Init.TIMode = SPI_TIMODE_DISABLE;
  hspi1.Init.CRCCalculation = SPI_CRCCALCULATION_DISABLE;
  hspi1.Init.CRCPolynomial = 7;
  hspi1.Init.CRCLength = SPI_CRC_LENGTH_DATASIZE;
  hspi1.Init.NSSPMode = SPI_NSS_PULSE_DISABLE;
  if (HAL_SPI_Init(&hspi1) != HAL_OK)
  {
    Error_Handler();
  }

}

/** Configure pins as 
        * Analog 
        * Input 
        * Output
        * EVENT_OUT
        * EXTI
*/
static void MX_GPIO_Init(void)
{

  GPIO_InitTypeDef GPIO_InitStruct;

  /* GPIO Ports Clock Enable */
  __HAL_RCC_GPIOA_CLK_ENABLE();
  __HAL_RCC_GPIOB_CLK_ENABLE();

  /*Configure GPIO pin Output Level */
  HAL_GPIO_WritePin(GPIOA, SPI1_CS_Pin|STICK_BUTTON_Pin, GPIO_PIN_SET);

  /*Configure GPIO pin Output Level */
  HAL_GPIO_WritePin(USER_LED_GPIO_Port, USER_LED_Pin, GPIO_PIN_SET);

  /*Configure GPIO pin : SPI1_CS_Pin */
  GPIO_InitStruct.Pin = SPI1_CS_Pin;
  GPIO_InitStruct.Mode = GPIO_MODE_OUTPUT_PP;
  GPIO_InitStruct.Pull = GPIO_NOPULL;
  GPIO_InitStruct.Speed = GPIO_SPEED_FREQ_LOW;
  HAL_GPIO_Init(SPI1_CS_GPIO_Port, &GPIO_InitStruct);

  /*Configure GPIO pin : STICK_BUTTON_Pin */
  GPIO_InitStruct.Pin = STICK_BUTTON_Pin;
  GPIO_InitStruct.Mode = GPIO_MODE_OUTPUT_OD;
  GPIO_InitStruct.Pull = GPIO_NOPULL;
  GPIO_InitStruct.Speed = GPIO_SPEED_FREQ_LOW;
  HAL_GPIO_Init(STICK_BUTTON_GPIO_Port, &GPIO_InitStruct);

  /*Configure GPIO pin : USER_LED_Pin */
  GPIO_InitStruct.Pin = USER_LED_Pin;
  GPIO_InitStruct.Mode = GPIO_MODE_OUTPUT_PP;
  GPIO_InitStruct.Pull = GPIO_NOPULL;
  GPIO_InitStruct.Speed = GPIO_SPEED_FREQ_LOW;
  HAL_GPIO_Init(USER_LED_GPIO_Port, &GPIO_InitStruct);

  /*Configure GPIO pin : USER_BUTTON_Pin */
  GPIO_InitStruct.Pin = USER_BUTTON_Pin;
  GPIO_InitStruct.Mode = GPIO_MODE_INPUT;
  GPIO_InitStruct.Pull = GPIO_PULLUP;
  HAL_GPIO_Init(USER_BUTTON_GPIO_Port, &GPIO_InitStruct);

}

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


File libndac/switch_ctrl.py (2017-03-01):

import time
import serial

JOYCON_BUTTONS_LEFT = ["du", "dd", "dl", "dr", "ls", "zl", "-", "cap", "lsl", "lsr", "syncl", "sbl"]
JOYCON_BUTTONS_RIGHT = ["a", "b", "x", "y", "rs", "zr", "+", "h", "rsl", "rsr", "syncr", "sbr"]

class switch_ctrl:
    def __init__(self, serial_port1, serial_port2):
        self.port1 = serial_port1
        self.port2 = serial_port2
        self.ser1 = serial.Serial()
        self.ser2 = serial.Serial()
        self.ser_left = serial.Serial()
        self.ser_right = serial.Serial()

    def connect(self):
        while 1:
            try:
                time.sleep(1.2)
                self.ser1.close()
                self.ser2.close()
                self.ser1 = serial.Serial(self.port1, 115200)
                print(self.port1 + " opened successfully")
                self.ser2 = serial.Serial(self.port2, 115200)
                print(self.port2 + " opened successfully")
                self.ser1.write("whoami\n".encode('utf-8'))
                ser1_result = self.ser1.readline().decode('utf-8')
                self.ser2.write("whoami\n".encode('utf-8'))
                ser2_result = self.ser2.readline().decode('utf-8')
                break
            except Exception as e:
                print("exception trying to connect: " + str(e))
                continue

        if ser1_result == ser2_result:
            print("ERROR: both boards are same side")
            exit()
        elif "LEFT" not in ser1_result and "RIGHT" not in ser1_result:
            print("ERROR: unknown board type on " + self.port1)
            exit()
        elif "LEFT" not in ser2_result and "RIGHT" not in ser2_result:
            print("ERROR: unknown board type on " + self.port2)
            exit()

        if "LEFT" in ser1_result:
            self.ser_left = self.ser1
            self.ser_right = self.ser2
        else:
            self.ser_left = self.ser2
            self.ser_right = self.ser1
        print("left joycon is: " + str(self.ser_left.port))
        print("right joycon is: " + str(self.ser_right.port))
        print("ports open successful")

    def disconnect(self):
        print("disconnecting...")
        self.reset()
        self.ser1.close()
        self.ser2.close()

    def send(self, ser_port, message):
        if len(message) <= 0:
            return
        try:
            ser_port.write(message.encode('utf-8'))
        except Exception as e:
            print("serial write error:\nport: " + str(ser_port.port) + "\nexception: " + str(e))
            self.connect()
        print(str(ser_port.port) + " sent: " + message)

    def recvln(self, ser_port):
        result = ''
        try:
            result = ser_port.readline().decode('utf-8')
        except Exception as e:
            print("serial read error:\nport: " + str(ser_port.port) + "\nexception: " + str(e))
            self.connect()
        print(str(ser_port.port) + " received: " + result)
        return result

    def check_error(self, left_message, right_message, left_result, right_result):
        if "ERROR" in left_result:
            raise ValueError('LEFT joycon\nsent: ' + str(left_message) + '\nreceived: ' + left_result + '\n')
        if "ERROR" in right_result:
            raise ValueError('RIGHT joycon\nsent: ' + str(right_message) + '\nreceived: ' + right_result + '\n')

    def button_click(self, duration_ms, button_list):
        left_message = ''
        right_message = ''
        left_result = ''
        right_result = ''
        left_queue = [x for x in button_list if x in JOYCON_BUTTONS_LEFT][:16]
        right_queue = [x for x in button_list if x in JOYCON_BUTTONS_RIGHT][:16]
        if len(left_queue) > 0:
            left_message = "bc " + str(duration_ms) + " "
            for item in left_queue:
                left_message += item + " "
            left_message += '\n'
        if len(right_queue) > 0:
            right_message = "bc " + str(duration_ms) + " "
            for item in right_queue:
                right_message += item + " "
            right_message += '\n'
        self.send(self.ser_left, left_message)
        self.send(self.ser_right, right_message)
        if len(left_message) > 0:
            left_result = self.recvln(self.ser_left)
        if len(right_message) > 0:
            right_result = self.recvln(self.ser_right)
        self.check_error(left_message, right_message, left_result, right_result)

    def button_stick_dual(self, duration_ms, button_list, x_left, x_right, y_left, y_right):
        pass

    def button_hold(self, button_list):
        left_message = ''
        right_message = ''
        left_result = ''
        right_result = ''
        left_queue = [x for x in button_list if x in JOYCON_BUTTONS_LEFT][:16]
        right_queue = [x for x in button_list if x in JOYCON_BUTTONS_RIGHT][:16]
        if len(left_queue) > 0:
            left_message = "bh "
            for item in left_queue:
                left_message += item + " "
            left_message += '\n'
        if len(right_queue) > 0:
            right_message = "bh "
            for item in right_queue:
                right_message += item + " "
            right_message += '\n'
        self.send(self.ser_left, left_message)
        self.send(self.ser_right, right_message)
        if len(left_message) > 0:
            left_result = self.recvln(self.ser_left)
        if len(right_message) > 0:
            right_result = self.recvln(self.ser_right)
        self.check_error(left_message, right_message, left_result, right_result)

    def button_release(self, button_list):
        left_message = ''
        right_message = ''
        left_result = ''
        right_result = ''
        left_queue = [x for x in button_list if x in JOYCON_BUTTONS_LEFT][:16]
        right_queue = [x for x in button_list if x in JOYCON_BUTTONS_RIGHT][:16]
        if len(left_queue) > 0:
            left_message = "br "
            for item in left_queue:
                left_message += item + " "
            left_message += '\n'
        if len(right_queue) > 0:
            right_message = "br "
            for item in right_queue:
                right_message += item + " "
            right_message += '\n'
        self.send(self.ser_left, left_message)
        self.send(self.ser_right, right_message)
        if len(left_message) > 0:
            left_result = self.recvln(self.ser_left)
        if len(right_message) > 0:
            right_result = self.recvln(self.ser_right)
        self.check_error(left_message, right_message, left_result, right_result)

    def button_release_all(self):
        message = 'bra\n'
        self.send(self.ser_left, message)
        self.send(self.ser_right, message)
        left_result = self.recvln(self.ser_left)
        right_result = self.recvln(self.ser_right)
        self.check_error(message, message, left_result, right_result)
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

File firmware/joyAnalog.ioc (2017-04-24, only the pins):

Mcu.UserName=STM32F072C8Tx
PA11.Signal=USB_DM
PA12.Signal=USB_DP
PA13.Signal=SYS_SWDIO
PA14.Signal=SYS_SWCLK
PA2.GPIO_Label=SPI1_CS
PA2.Signal=GPIO_Output
PA3.GPIO_Label=STICK_BUTTON
PA3.Signal=GPIO_Output
PA4.Signal=COMP_DAC1_group
PA5.Signal=COMP_DAC2_group
PA6.Signal=SPI1_MISO
PA7.Signal=SPI1_MOSI
PB11.GPIO_Label=USER_LED
PB11.Signal=GPIO_Output
PB3.Signal=SPI1_SCK
PB6.Signal=I2C1_SCL
PB7.Signal=I2C1_SDA
PB9.GPIO_Label=USER_BUTTON
PB9.Signal=GPIO_Input

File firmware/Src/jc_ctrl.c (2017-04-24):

#include <stdio.h>
#include <string.h>
#include <stdlib.h>
#include "jc_ctrl.h"

uint16_t button_status;
uint16_t stick_idle_dac_val;
float dac_modifier;

void jc_ctrl_init(void)
{
  button_status = 0;
  button_write(button_status);
  stick_idle_dac_val = b_to_uint16t(eeprom_read(EEPROM_ADC_CALIB_MSB_ADDR), eeprom_read(EEPROM_ADC_CALIB_LSB_ADDR));
  dac_modifier = (float)stick_idle_dac_val / 127;
}

void button_write(uint16_t value)
{
  uint8_t spi_buf[2];
  spi_buf[0] = value & 0xff;
  spi_buf[1] = (value >> 8);
  spi_cs_low();
  HAL_SPI_Transmit(spi1_ptr, spi_buf, 2, 100);
  spi_cs_high();
  if(value & 0x20)
    HAL_GPIO_WritePin(STICK_BUTTON_GPIO_Port, STICK_BUTTON_Pin, GPIO_PIN_RESET);
  else
    HAL_GPIO_WritePin(STICK_BUTTON_GPIO_Port, STICK_BUTTON_Pin, GPIO_PIN_SET);
}


void dac_write(uint8_t x_8b, uint8_t y_8b)
{
  uint32_t x_12b = (uint32_t)((float)x_8b * dac_modifier);
  uint32_t y_12b = (uint32_t)((float)y_8b * dac_modifier);
  if(dac_ptr->State == HAL_DAC_STATE_RESET)
    stm32_dac_init();
  HAL_DACEx_DualSetValue(dac_ptr, DAC_ALIGN_12B_R, x_12b, y_12b);
}

void stick_release(void)
{
  if(dac_ptr->State == HAL_DAC_STATE_RESET)
    stm32_dac_init();
  HAL_DACEx_DualSetValue(dac_ptr, DAC_ALIGN_12B_R, stick_idle_dac_val, stick_idle_dac_val);
}

void stick_disengage(void)
{
  if(dac_ptr->State != HAL_DAC_STATE_RESET)
  {
    HAL_DAC_Stop(dac_ptr, DAC_CHANNEL_1);
    HAL_DAC_Stop(dac_ptr, DAC_CHANNEL_2);
    HAL_DAC_DeInit(dac_ptr);
  }
}

void release_all_button(void)
{
  button_status = 0;
  button_write(button_status);
}

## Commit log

2016-12-23 adjust silkscreen
    [switchmod.brd]
2016-12-24 adjusted header so they line up with 0.1in grid
    [switchmod.brd]
2016-12-26 board cleanup
    [switchmod.brd]
2016-12-27 slikscreen cleanup
    [switchmod.brd]
2017-01-18 minor board improvements
    [switchmod.brd, switchmod.sch]
2017-01-18 renamed to NintenDAC
    [nintendac.brd, nintendac.sch]
2017-01-18 logo adjustment
    [nintendac.brd]
2017-01-21 vcc trace update
    [nintendac.brd]
2017-01-21 added a resistor on ref
    [nintendac.brd, nintendac.sch]
2017-01-22 silkscreen cleanup
    [nintendac.brd]
2017-01-22 stm32 dac datasheet
2017-02-14 added mini board
    [nintendac.brd, nintendac.sch]
2017-02-14 updated mini layout
    [nintendac.brd, nintendac.sch]
2017-02-18 added watchdog
    [nintendac.brd, nintendac.sch, nintendac_mini.brd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]
2017-02-20 updated libndac
    [nintendac_mini.brd]
2017-02-21 updated power control on mini
    [nintendac_mini.brd, nintendac_mini.sch]
2017-02-21 standby wakeup test
    [nintendac_mini.brd]
2017-02-22 added EEPROM
    [nintendac.brd, nintendac.sch]
2017-02-22 removed wkup from headers
    [nintendac.brd, nintendac.sch, nintendac_mini.brd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]
2017-02-24 added board version check
    [nintendac.brd]
2017-02-27 moved logo
    [nintendac_mini.brd]
2017-02-28 adding dual board support
2017-02-28 dual board support for libndac
2017-03-01 cleaned up firmware for full sized board
2017-04-03 started working on analog switch version
    [nintendac_mini.brd, nintendac_mini.sch]
2017-04-03 continue working on AS
    [nintendac_mini.brd, nintendac_mini.sch]
2017-04-04 finished design, changed name
    [joyAnalog.brd, joyAnalog.sch, nintendac.brd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]
2017-04-13 firmware update, fixed pcb bug
    [joyAnalog.brd, joyAnalog.sch]
2017-04-14 multi voltage
    [joyAnalog.brd]
2017-10-18 cleanup, more documentations
    [joyAnalog.brd, joyAnalog.sch, nintendac.brd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]

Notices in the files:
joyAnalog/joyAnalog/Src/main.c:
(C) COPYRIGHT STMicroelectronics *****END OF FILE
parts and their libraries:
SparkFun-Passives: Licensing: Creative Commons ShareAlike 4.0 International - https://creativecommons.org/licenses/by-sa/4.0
